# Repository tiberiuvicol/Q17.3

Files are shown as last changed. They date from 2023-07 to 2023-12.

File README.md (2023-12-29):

# Q17.3 - more than an audiophile approach to perfect sound

Q17.3 is a continuation of the <a href="https://github.com/tiberiuvicol/Q17-audiophile-amplifier">Q17 class B amplifier</a> based on current dumping principle.<br>
Use KiCad 7, or later, to open and edit source files.  KiCad 7 can be downloaded from CERN, https://www.kicad.org<br>
<b>LTSpice</b> - contain simulation asc file<br>

Q17 3

<br>
Click & Order your Q17.3 parts @ digikey https://www.digikey.co.uk/en/mylists/list/O9YXGXU6LF <br>
For STEREO or MULTICHANNEL multiply the order with the same parts. <br>
You may order your PCB at 
<a href="https://www.pcbway.com/project/shareproject/Q17_3_more_than_an_audiophile_approach_5a49a5dd.html">PCB from PCBWay</a>
<br>
What is new ? <br>
Operational was changed to OPA828. This is one of the few SiGe devices on the market, with terrific performance and most important, sound quality is exceptional.
Current mirror was replaced with NDC7003P (PJS6839 is an alternative). This have 2 matched p-mos transistors on same substrate with same thermal Vgs deviation.<br>
Furthermore, by adding Q7, current mirror was upgraded to a Wilson one. This improve mirror stability and class A stage operation at high frequency.
In an atempt to make the amplifier more "popular", I have adopted jellybean parts as IRFP240/IRFP9240, 2N4401/2N4403 and 2N5551/2N5401. These are widely available from various manufacturers.
First stage after OPA828 is now a modified "a la" Borbely cascode, made with a well known jfet LSK170B/2SK170B and a depletion mosfet DN2535/DN2540. 
In addition, R10 and R13 have been reduced to 9R1. In case IRFP's get too hot (over 60Celsius), you may increase R10 and R13 to 10ohm.<br>
With this modifications, Q17 performance was considerably improved, both in measurement and listening.
<br>
If you have built this amplifier I would love to see your Q17 implementation. :-) <br>
<br>
Enjoy and thank you for reading !

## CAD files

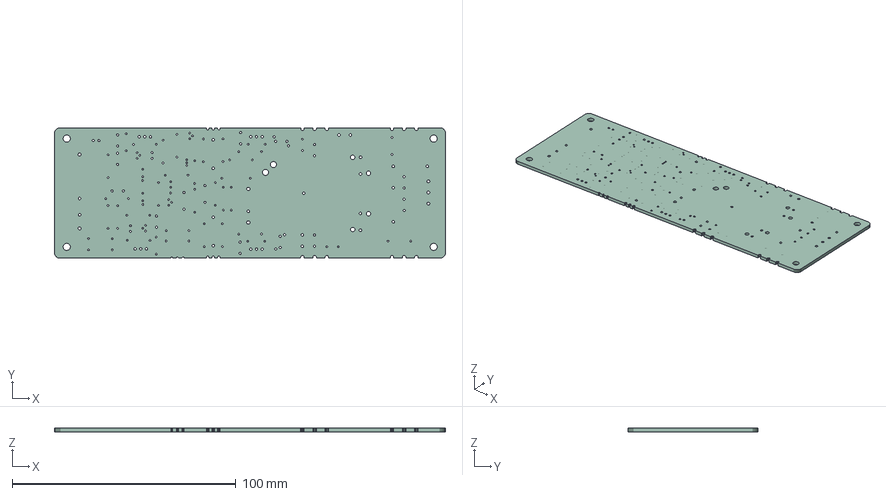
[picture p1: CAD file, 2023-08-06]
Q17.3.step
174.7 x 58.3 x 1.58 mm

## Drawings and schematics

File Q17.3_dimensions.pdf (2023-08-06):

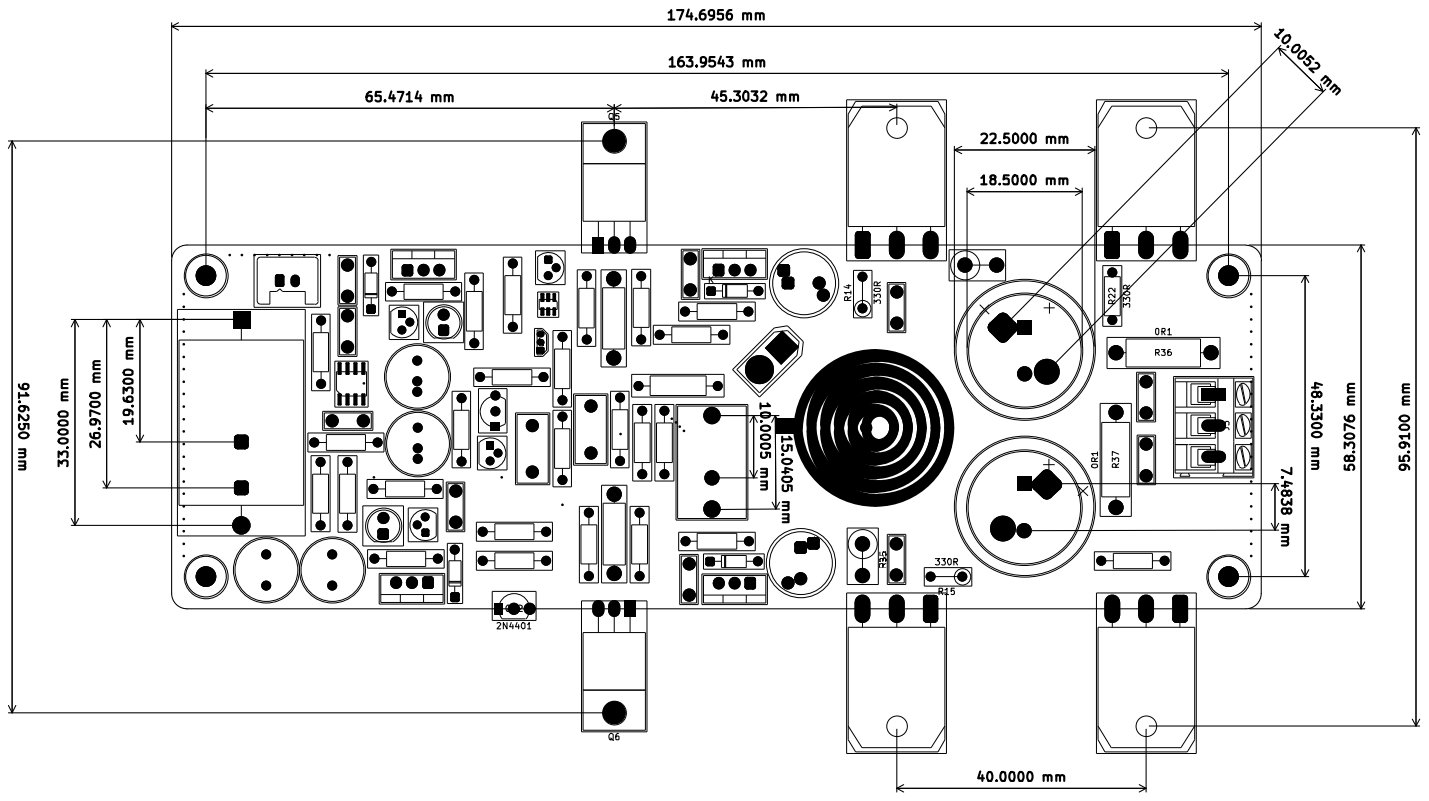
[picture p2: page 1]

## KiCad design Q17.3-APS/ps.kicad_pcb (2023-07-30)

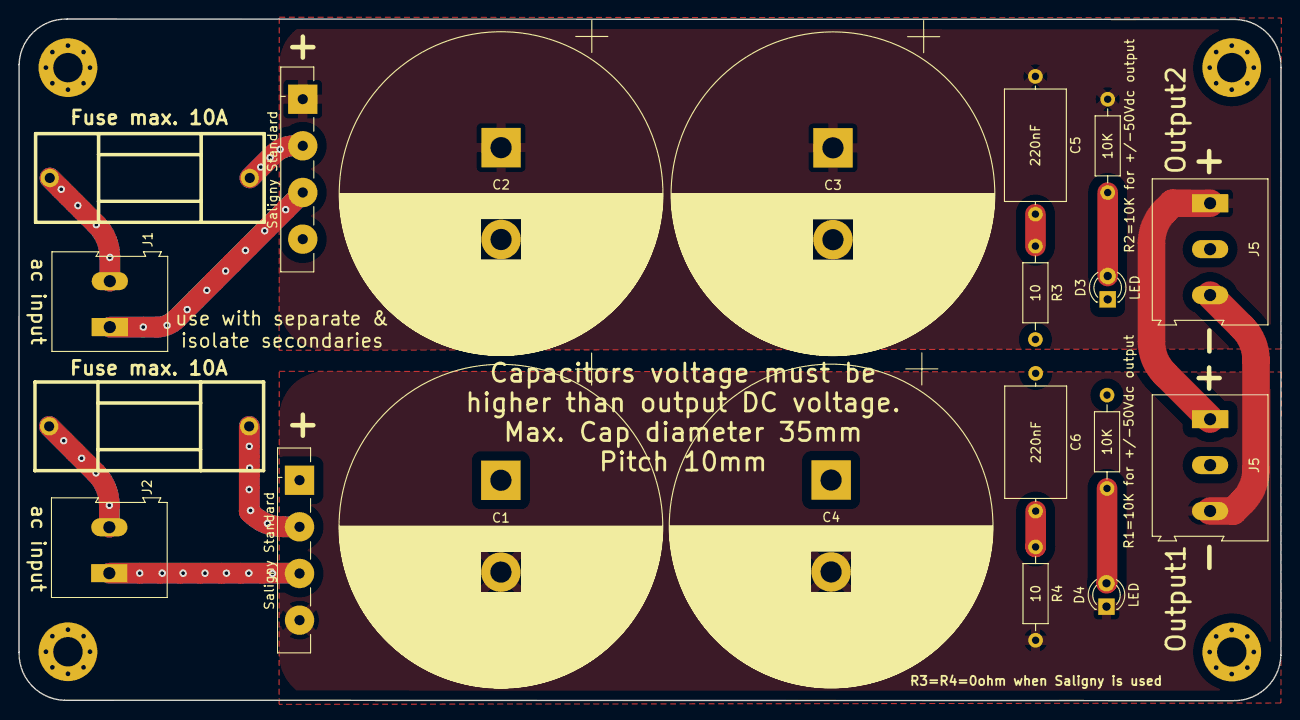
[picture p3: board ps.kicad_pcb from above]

Board: 2 copper layers, 137.4 x 74.2 mm, 20 parts (0 on the bottom side), 11 nets.

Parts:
C1, C2, C3, C4: C_Polarized; CP_Radial_D35.0mm_P10.00mm_SnapIn
C5, C6: 220nF; C_Axial_L12.0mm_D6.5mm_P15.00mm_Horizontal
D3, D4: LED; LED_D3.0mm
F1, F2: Fuse max. 10A; fuse_holder_CQ-2
J1, J2: Conn_01x02_Female; TerminalBlock_Altech_AK300-2_P5.00mm
J5, J5#2: Conn_01x03_Female; TerminalBlock_Altech_AK300-3_P5.00mm
R1=10K for +/-50Vdc output, R2=10K for +/-50Vdc output: 10K; R_Axial_DIN0207_L6.3mm_D2.5mm_P10.16mm_Horizontal
R3, R4: 10; R_Axial_DIN0207_L6.3mm_D2.5mm_P10.16mm_Horizontal
Saligny Standard: Active_Bridge_+AA-; Diode_Bridge_Vishay_GBU
Saligny Standard#2: Active_Bridge_+AA-; Diode_Bridge_Vishay_GBU

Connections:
GNDPWR: C1.1, C2.2, C3.2, C4.1, C6.1, D3.1 (K), J5.2, J5#2.2, R1=10K for +/-50Vdc output.1, R3.2, Saligny Standard.4 (-), Saligny Standard#2.1 (+)
unnamed: C5.2, R3.1
unnamed: C6.2, R4.1
unnamed: F1.2, Saligny Standard.2 (~~)
unnamed: J1.1, Saligny Standard.3 (~~)
unnamed: F2.2, Saligny Standard#2.2 (~~)
unnamed: J2.1, Saligny Standard#2.3 (~~)
unnamed: C1.2, C4.2, D4.1 (K), J5.3, J5#2.3, R4.2, Saligny Standard#2.4 (-)
unnamed: D3.2 (A), R2=10K for +/-50Vdc output.2
unnamed: D4.2 (A), R1=10K for +/-50Vdc output.2
unnamed: C2.1, C3.1, C5.1, J5.1, J5#2.1, R2=10K for +/-50Vdc output.1, Saligny Standard.1 (+)

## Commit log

2023-07-30 Create KiCad source
2023-07-30 KiCad source files
    PCB KiCad source files
    [Q17.3.kicad_sch]
2023-07-30 KiCAD source files
    PCB KiCad source files. Open with version 7.
    [Q17.3.kicad_sch]
2023-08-06 STEP file
    [Q17.3.step]
